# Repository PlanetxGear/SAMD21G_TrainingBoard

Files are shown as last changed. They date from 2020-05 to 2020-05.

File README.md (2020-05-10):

# Microchip SAMD21G Training Board for 「SAMファミリ活用ガイドブック」.
---
## Description
後閑哲也氏の著書[ＳＡＭファミリ活用ガイドブック][1](ISBN 978-4-297-11291-2)に出てくるトレーニングボードをKiCADで書き起こした回路図とガーバーデータです。
これは[KiCAD][2]によって描かれています。　この資料が皆さんの学習の一助となれば幸いです。

## Picture
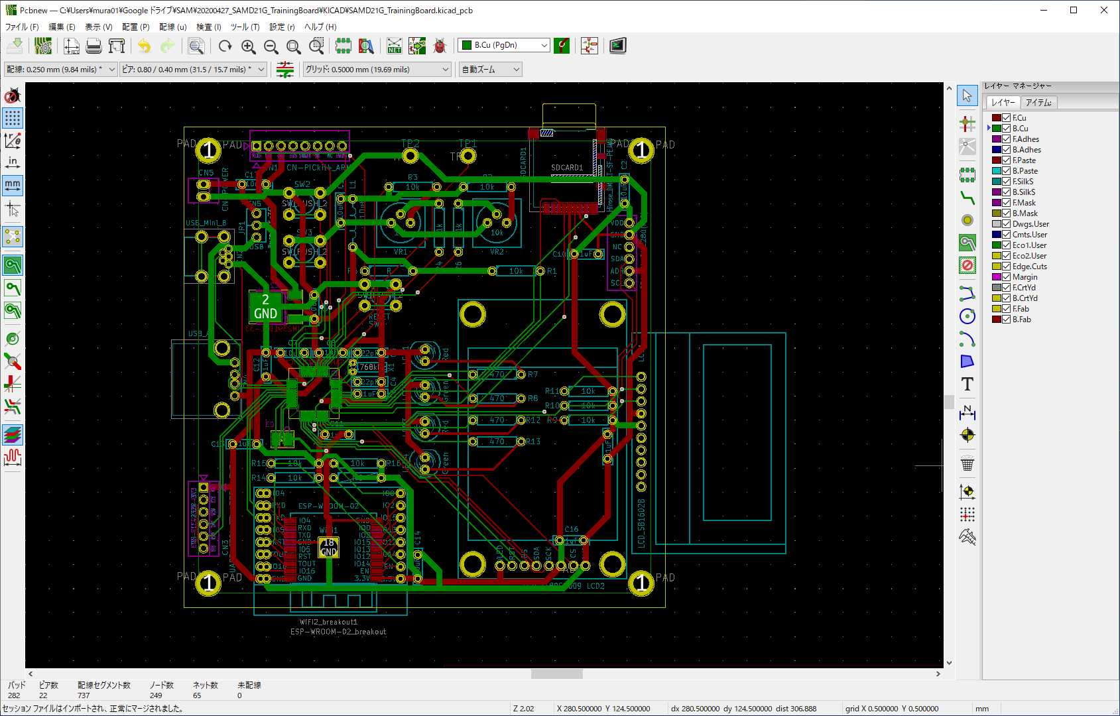
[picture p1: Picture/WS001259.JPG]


## References.
 * <https://www.microchip.com/wwwproducts/en/ATsamd21g18>
 * <http://www.picfun.com/picbookZ3.html>
 * <https://gihyo.jp/book/2020/978-4-297-11291-2>

## Licence
[MIT]<https://en.wikipedia.org/wiki/MIT_License> <https://ja.wikipedia.org/wiki/MIT_License>

## Author
Hiroshi Murakami  
<https://www.planetxgear.com/>  

[1]: https://gihyo.jp/book/2020/978-4-297-11291-2 
[2]: https://kicad-pcb.org/

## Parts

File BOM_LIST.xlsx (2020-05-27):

■SAMファミリ活用ガイドブック、トレーニングボード部品表 2020/05/07
※価格は、2020/05/07時点の調査によるものです。
※プリント基板の導通確認はできていません。
ref | value5 | part | Part Name | 購入先 | 購入先コード | 数量 | 単価 | 金額 | 備考1
IC1 | SAMD21G18A | SAMD21G18A | SAMD21G18A | 秋月電子通商 | I-09837 | 1 | 530 | 530
IC2 | NJM2391DL1-33 | NJM2391DL1-33 | NJM2391DL1-33 | 秋月電子通商 | I-02252 | 1 | 50 | 50 | 4個入り￥200
IC3 | GT20L16J1Y | GT20L16J1Y | GT20L16J1Y | スイッチサイエンス | SSCI-022729 | 1 | 155 | 155 | 2個入り￥310(税抜き)
LCD1 | LCD_SB1602B | LCD_I2C_SB1602B | LCD SB1602B | ストロベリーリナックス | 27001 | 1 | 667 | 667
LCD2 | LCD_Z180SN009 | LCD_Z180SN009 | LCD Z180SN009 | アイテンドー | M-Z18SPI-2PB | 1 | 950 | 950
LED1 | Red | LED | LED 5mm (OSDR5113A) | 秋月電子通商 | I-11655 | 1 | 20 | 20
LED2 | Green | LED | LED 5mm (OSNG5113A) | 秋月電子通商 | I-11656 | 1 | 20 | 20
LED3 | Red | LED | LED 5mm (OSDR5113A) | 秋月電子通商 | I-11655 | 1 | 20 | 20
LED4 | Green | LED | LED 5mm (OSNG5113A) | 秋月電子通商 | I-11656 | 1 | 20 | 20
SDCARD1 | Hirose_DM3AT-SF-PEJM5 | SD_CARD_microsdSD_HC_Hirose_DM3AT-SF-PEJM5 | microsdSD_HC_Hirose_DM3AT-SF-PEJM5 | 秋月電子通商 | C-02395 | 1 | 140 | 140
SE1 | CN-BME280(I2C) | CN-BME280(I2C) | BME280 | 秋月電子通商 | K-09421 | 1 | 1080 | 1080
SW1 | SW_PUSH_2 | SW_PUSH | 基板タクトスイッチ(赤) | 秋月電子通商 | P-03646 | 1 | 10 | 10
SW2 | SW_PUSH_2 | SW_PUSH | 基板タクトスイッチ(黒) | 秋月電子通商 | P-03647 | 1 | 10 | 10
SW3 | SW_PUSH_2 | SW_PUSH | 基板タクトスイッチ(黒) | 〃 | 〃 | 1 | 10 | 10
TP1 | TP1 | CN-1 | チェック端子(赤) | 秋月電子通商 | P-07588 | 1 | 20 | 20 | 10個入り￥200
TP2 | TP2 | CN-1 | チェック端子(黒) | 秋月電子通商 | P-07591 | 1 | 20 | 20 | 10個入り￥200
VR1 | 10k | RVR | TSR3386K-EY5-103TR | 秋月電子通商 | P-06110 | 1 | 50 | 50
VR2 | 10k | RVR | 〃 | 〃 | 〃 | 1 | 50 | 50
WiFi1 | ESP-WROOM-02 | ESP-WROOM-02 | ESP-WROOM-02 | 秋月電子通商 | M-09607 | 1 | 250 | 250
(WiFi2_breakout1) | ESP-WROOM-02_breakout | (ESP-WROOM-02) | (ESP-WROOM-02ピッチ変換キット) | (秋月電子通商/スイッチサイエンス) | (K-13646/SSCI-023474) | (1) | (580/842) |  | ※不要
X1 | 32.768kHz | Crystal | VT200,32.768kHz | 秋月電子通商 | P-04005 | 1 | 30 | 30
L1 | 10uH | L | マイクロインダクター 10uF | 秋月電子通商 | P-04932 | 1 | 10 | 10 | 10個入り￥100
C1 | 10uF | C | 積層セラミックコンデンサ5mmピッチ 10uF | 秋月電子通商 | P-03095 | 1 | 20 | 20 | 10個入り￥200
C2 | 10uF | C | 〃 | 〃 | 〃 | 1 | 20 | 20
C5 | 10uF | C | 〃 | 〃 | 〃 | 1 | 20 | 20
C7 | 10uF | C | 〃 | 〃 | 〃 | 1 | 20 | 20
C14 | 10uF | C | 〃 | 〃 | 〃 | 1 | 20 | 20
C17 | 10uF | C | 〃 | 〃 | 〃 | 1 | 20 | 20
C6 | 1uF | C | 積層セラミックコンデンサ5mmピッチ 1uF | 秋月電子通商 | P-03093 | 1 | 10 | 10 | 10個入り￥100
C8 | 1uF | C | 〃 | 〃 | 〃 | 1 | 10 | 10
C10 | 1uF | C | 〃 | 〃 | 〃 | 1 | 10 | 10
C11 | 1uF | C | 〃 | 〃 | 〃 | 1 | 10 | 10
C12 | 1uF | C | 〃 | 〃 | 〃 | 1 | 10 | 10
C13 | 1uF | C | 〃 | 〃 | 〃 | 1 | 10 | 10
C15 | 1uF | C | 〃 | 〃 | 〃 | 1 | 10 | 10
C16 | 1uF | C | 〃 | 〃 | 〃 | 1 | 10 | 10
C3 | 22pF | C | 積層セラミックコンデンサ5mmピッチ 22pF | 秋月電子通商 | P-08094 | 1 | 10 | 10 | 10個入り￥100
C4 | 22pF | C | 〃 | 〃 | 〃 | 1 | 10 | 10
CN2 | USB_Mini_B | CN_USB_Mini_B | USB type B Mini connector | 秋月電子通商 | C-02235 | 1 | 50 | 50 | 4個入り￥200
CN4 | USB_A | CN_USB_A | USB type A connector | 秋月電子通商 | C-11551 | 1 | 50 | 50
CN1 | CN-PICkit4_ARM | CN-PICkit4_ARM | ピンヘッダ | - | - |  |  | 0 | ※下記ピンヘッダ切断
CN3 | UART-FTDI-TTL-232R-3V3 | CN-UART-FTDI-TTL-232R-3V3 | ピンヘッダ | - | - |  |  | 0 | 〃
CN5 | CN-POWER | CN-POWER | ピンヘッダ | - | - |  |  | 0 | 〃
JP1 | Jumper_3P | Jumper_NO_Small_3P | ピンヘッダ | - | - |  |  | 0 | 〃
 |  |  | ピンヘッダ L型 1 x 40 |  | C-01627 | 1 | 50 | 50
 |  |  | 丸ピンＩＣ用連結ソケット |  | P-01382 | 1 | 230 | 230
 |  |  | 丸ピンＩＣ用ソケット |  | P-01591 | 1 | 150 | 150
－ | － | － | ジャンパーピン赤 | 秋月電子通商 | P-03688 | 1 | 4 | 4 | 25個入り￥100
R1 | 10k | R | カーボン抵抗 1/6W 10kΩ | 秋月電子通商 | R-16103 | 1 | 1 | 1 | 100個入り￥100
R2 | 10k | R | 〃 | 〃 | 〃 | 1 | 1 | 1
R3 | 10k | R | 〃 | 〃 | 〃 | 1 | 1 | 1
R5 | 10k | R | 〃 | 〃 | 〃 | 1 | 1 | 1
R9 | 10k | R | 〃 | 〃 | 〃 | 1 | 1 | 1
R10 | 10k | R | 〃 | 〃 | 〃 | 1 | 1 | 1
R11 | 10k | R | 〃 | 〃 | 〃 | 1 | 1 | 1
R14 | 10k | R | 〃 | 〃 | 〃 | 1 | 1 | 1
R15 | 10k | R | 〃 | 〃 | 〃 | 1 | 1 | 1
R16 | 10k | R | 〃 | 〃 | 〃 | 1 | 1 | 1
R4 | 1k | R | カーボン抵抗 1/6W 1kΩ | 秋月電子通商 | R-16102 | 1 | 1 | 1 | 100個入り￥100
R6 | 1k | R | 〃 | 〃 | 〃 | 1 | 1 | 1
R7 | 470 | R | カーボン抵抗 1/6W 470Ω | 秋月電子通商 | R-16471 | 1 | 1 | 1 | 100個入り￥100
R8 | 470 | R | 〃 | 〃 | 〃 | 1 | 1 | 1
R12 | 470 | R | 〃 | 〃 | 〃 | 1 | 1 | 1
R13 | 470 | R | 〃 | 〃 | 〃 | 1 | 1 | 1
R99 | NC | R | － | － | － |  |  | 0 | ※不要
 |  |  |  |  |  | 部品金額合計 |  | 4882 | 円
 |  |  |  |  |  | 消費税 |  | 488.2 | 円
 |  |  |  |  |  | 小計 |  | 5370.2 | 円
 |  |  | プリント基板(10枚,送料込み)=$29.9+$17.45=$47.35 |  |  | 1 | 527 | 527 | (￥5269/10枚=￥527)
 |  |  |  |  |  | 送料・梱包代（レターパックライト） |  | 370 | 円
 |  |  |  |  |  | 合計 |  | 6267.2 | 円

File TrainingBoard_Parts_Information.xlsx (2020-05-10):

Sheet: SAMD21G18A
1 | PA00/XIN32
2 | PA01/XOUT32
3 | PA02/AN0/VO
4 | PA03/AN1
5 | GNDA
6 | VDDA
7 | PB08/AN2
8 | PB09/AN3
9 | PA04/AN4
10 | PA05/AN5
11 | PA06/AN6
12 | PA07/AN7
13 | PA08/I2C
14 | PA09/I2C
15 | PA10
16 | PA11
17 | VDDIO
18 | GND
19 | PB10
20 | PB11
21 | PA12/I2C
22 | PA13/I2C
23 | PA14/XIN
24 | PA15/XOUT
25 | PA16/I2C
26 | PA17/I2C
27 | PA18/AC
28 | PA19/AC
29 | PA20
30 | PA21
31 | PA22/I2C
32 | PA23/I2C
33 | PA24/D-
34 | PA25/D+
35 | GND1
36 | VDDIO1
37 | PB22
38 | PB23
39 | PA27
40 | RSTEN
41 | PA28
42 | GND2
43 | VDDCORE
44 | VDDIN
45 | PA30/SWCLK
46 | PA31/SWDIO
47 | PB02/AN10
48 | PB03/AN11
PICkit4とSAMの接続
PICkit4ユーザガイドAppendix

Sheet: GT20L16J1Y
日本語フォントROM GT20L16J1Y チップ 2個入り
 | https://www.switch-science.com/catalog/2272/
 | http://www.genitop.com/admin/upload/20150511144125736.pdf
 | コード番号 | SSCI-022729

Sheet: Sheet1
★1.8インチ★TFT液晶with基板★SPI★ [M-Z18SPI-2PB]
 | Z180SN009
 | https://www.aitendo.com/product/15420
 | 基板寸法：58x35x1.2mm

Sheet: ESP-WROOM-02
ESP-WROOM-02ピッチ変換済みモジュール《シンプル版》
 | https://www.switch-science.com/catalog/2341/
 | http://doc.switch-science.com/schematic/ESP-WROOM-02/ESP-WROOM-02_breakout_simple.pdf
 | ESP-WROOM-02モジュールと各端子の接続
 | ESP-WROOM-02 | 当モジュール
 | 3V3 | 3V3
 | EN | EN
 | IO14 | 未接続
 | IO12 | 未接続
 | IO13 | 未接続
 | IO15 | SJ1経由でGNDに接続（裏面）
 | IO2 | SJ2（裏面）、IO2
 | IO0 | SJ3（裏面）、IO0
 | GND | GND
 | IO4 | 未接続
 | RXD | RXD
 | TXD | TXD
 | GND | GND
 | IO5 | 未接続
 | RST | RST
 | TOUT | 未接続
 | IO16 | 未接続
 | GND | GND
Ｗｉ－Ｆｉモジュール ＥＳＰ－ＷＲＯＯＭ－０２
 | http://akizukidenshi.com/catalog/g/gM-09607/
 | ESP-WROOM-02(4MB)]
 | 通販コード | M-09607
ＥＳＰ－ＷＲＯＯＭ－０２ピッチ変換キット
 | AE-ESP-WROOM-02-1100MIL
 | 通販コード | K-13646
ESP-WROOM-02ピッチ変換済みモジュール《フル版》
 | https://www.switch-science.com/catalog/2347/

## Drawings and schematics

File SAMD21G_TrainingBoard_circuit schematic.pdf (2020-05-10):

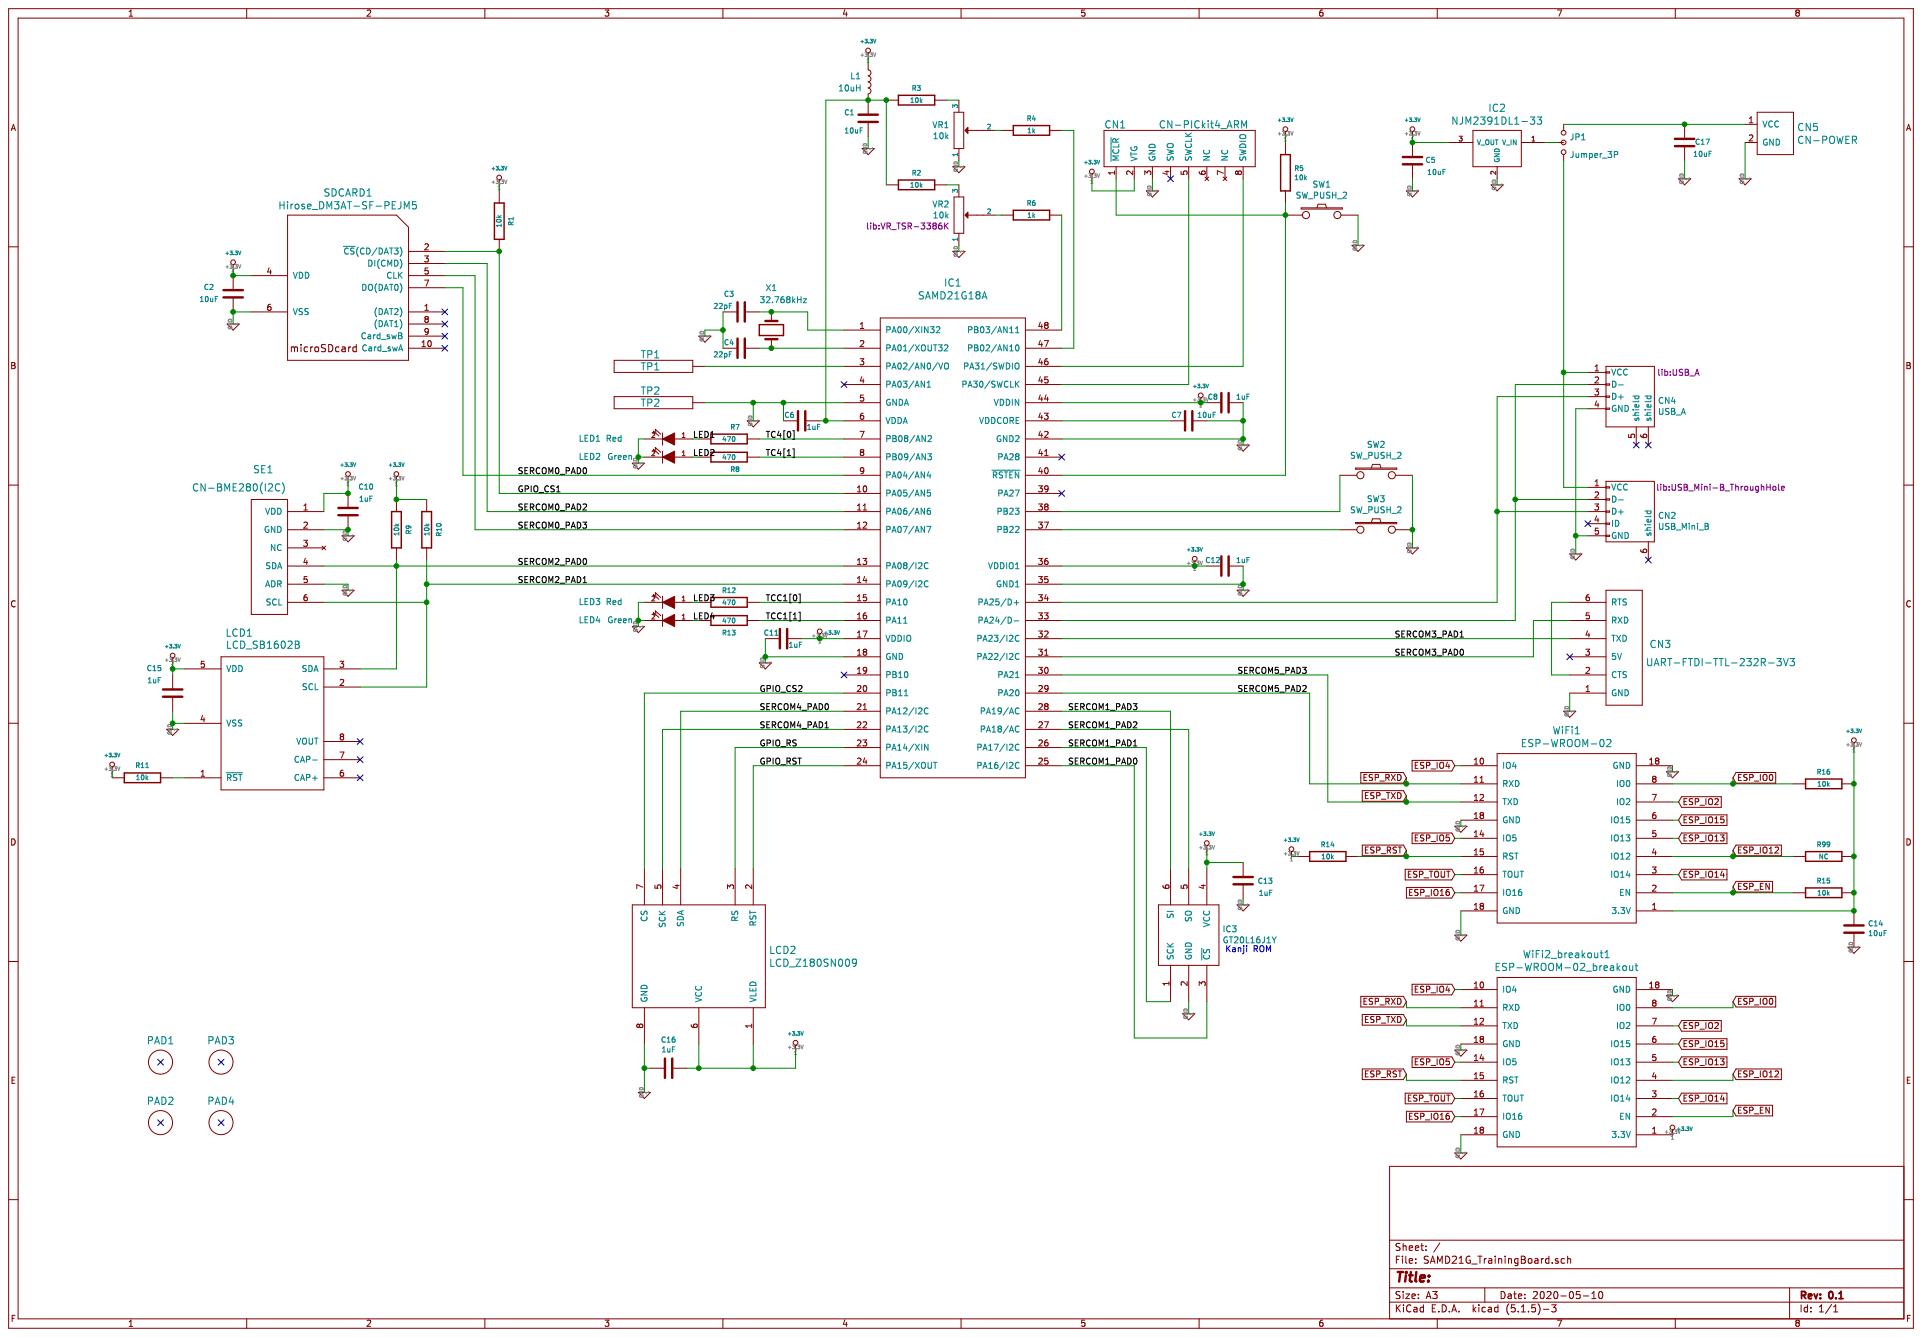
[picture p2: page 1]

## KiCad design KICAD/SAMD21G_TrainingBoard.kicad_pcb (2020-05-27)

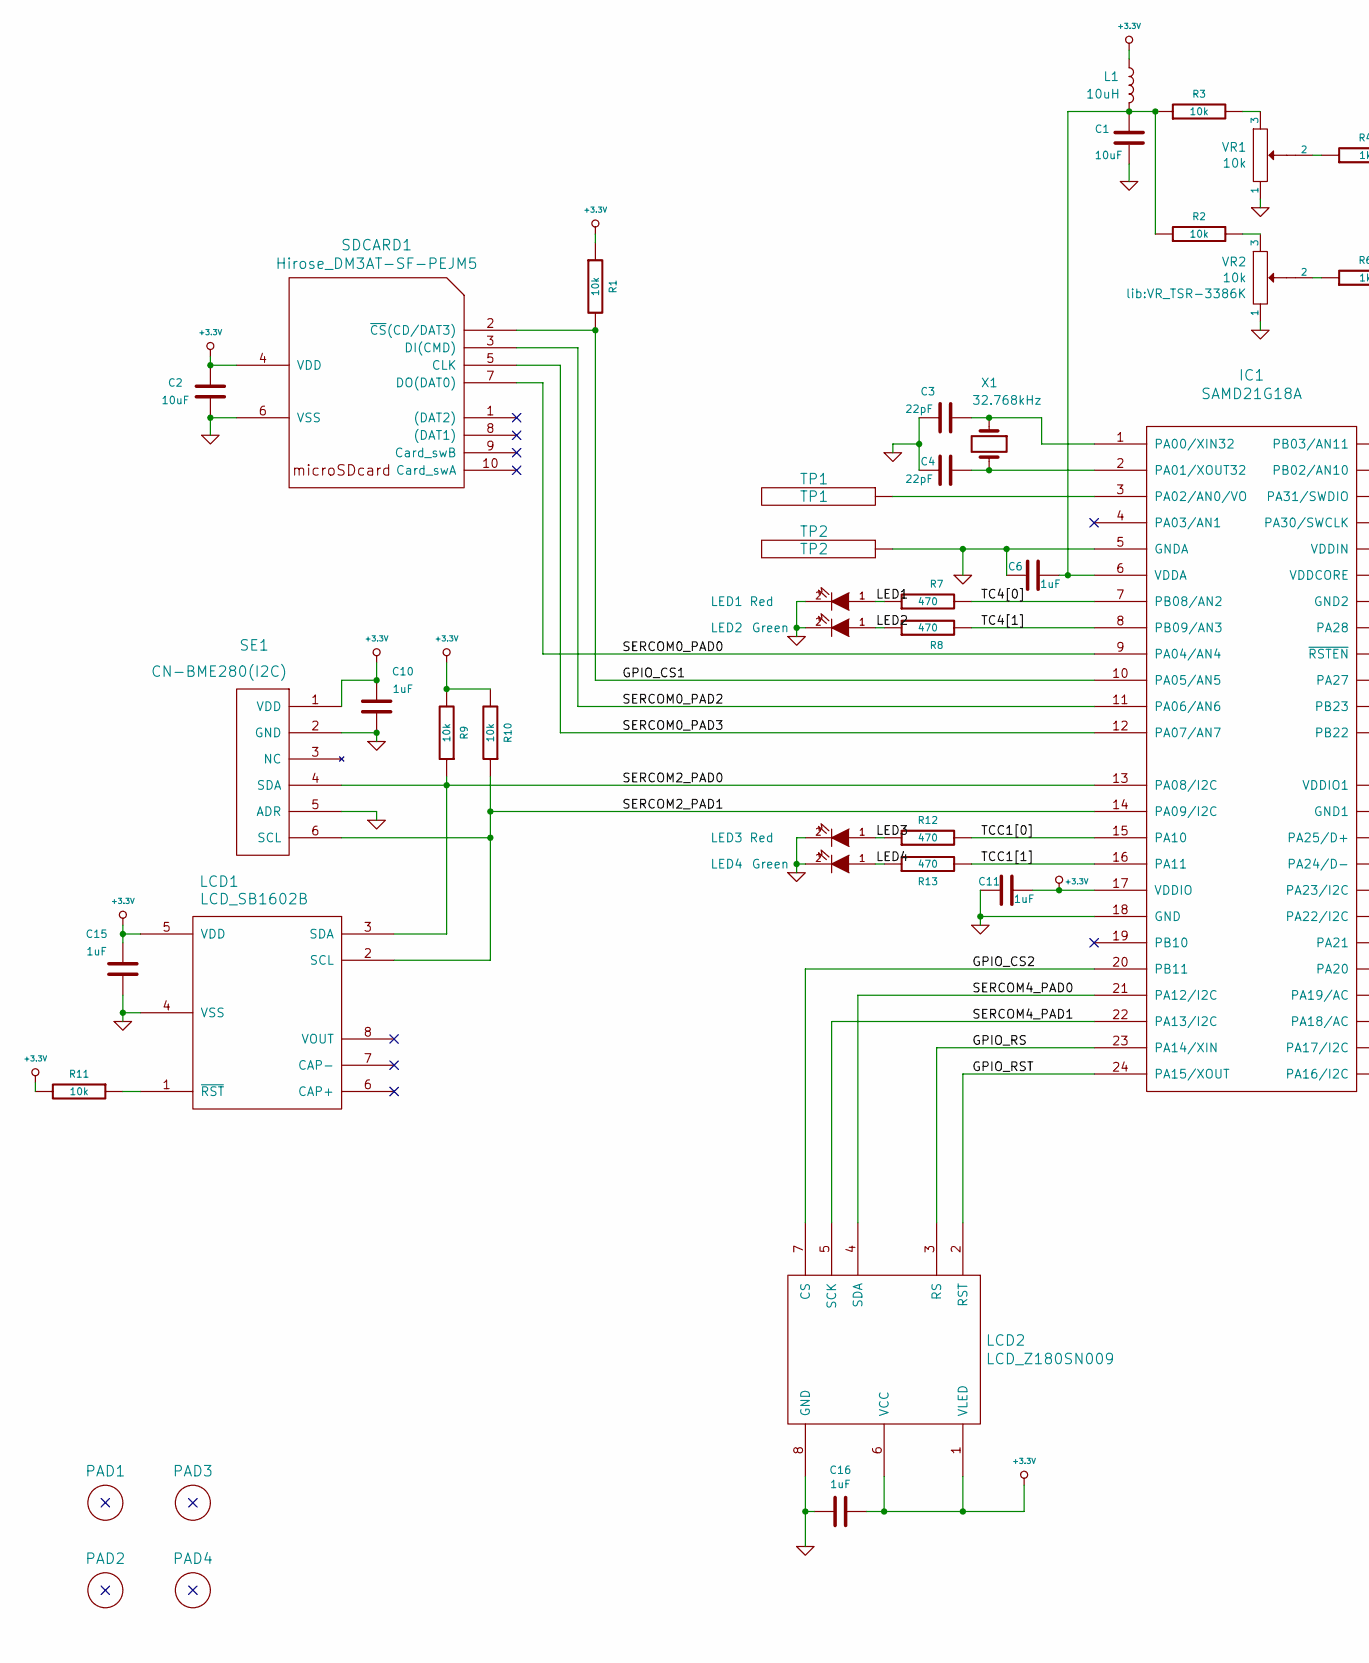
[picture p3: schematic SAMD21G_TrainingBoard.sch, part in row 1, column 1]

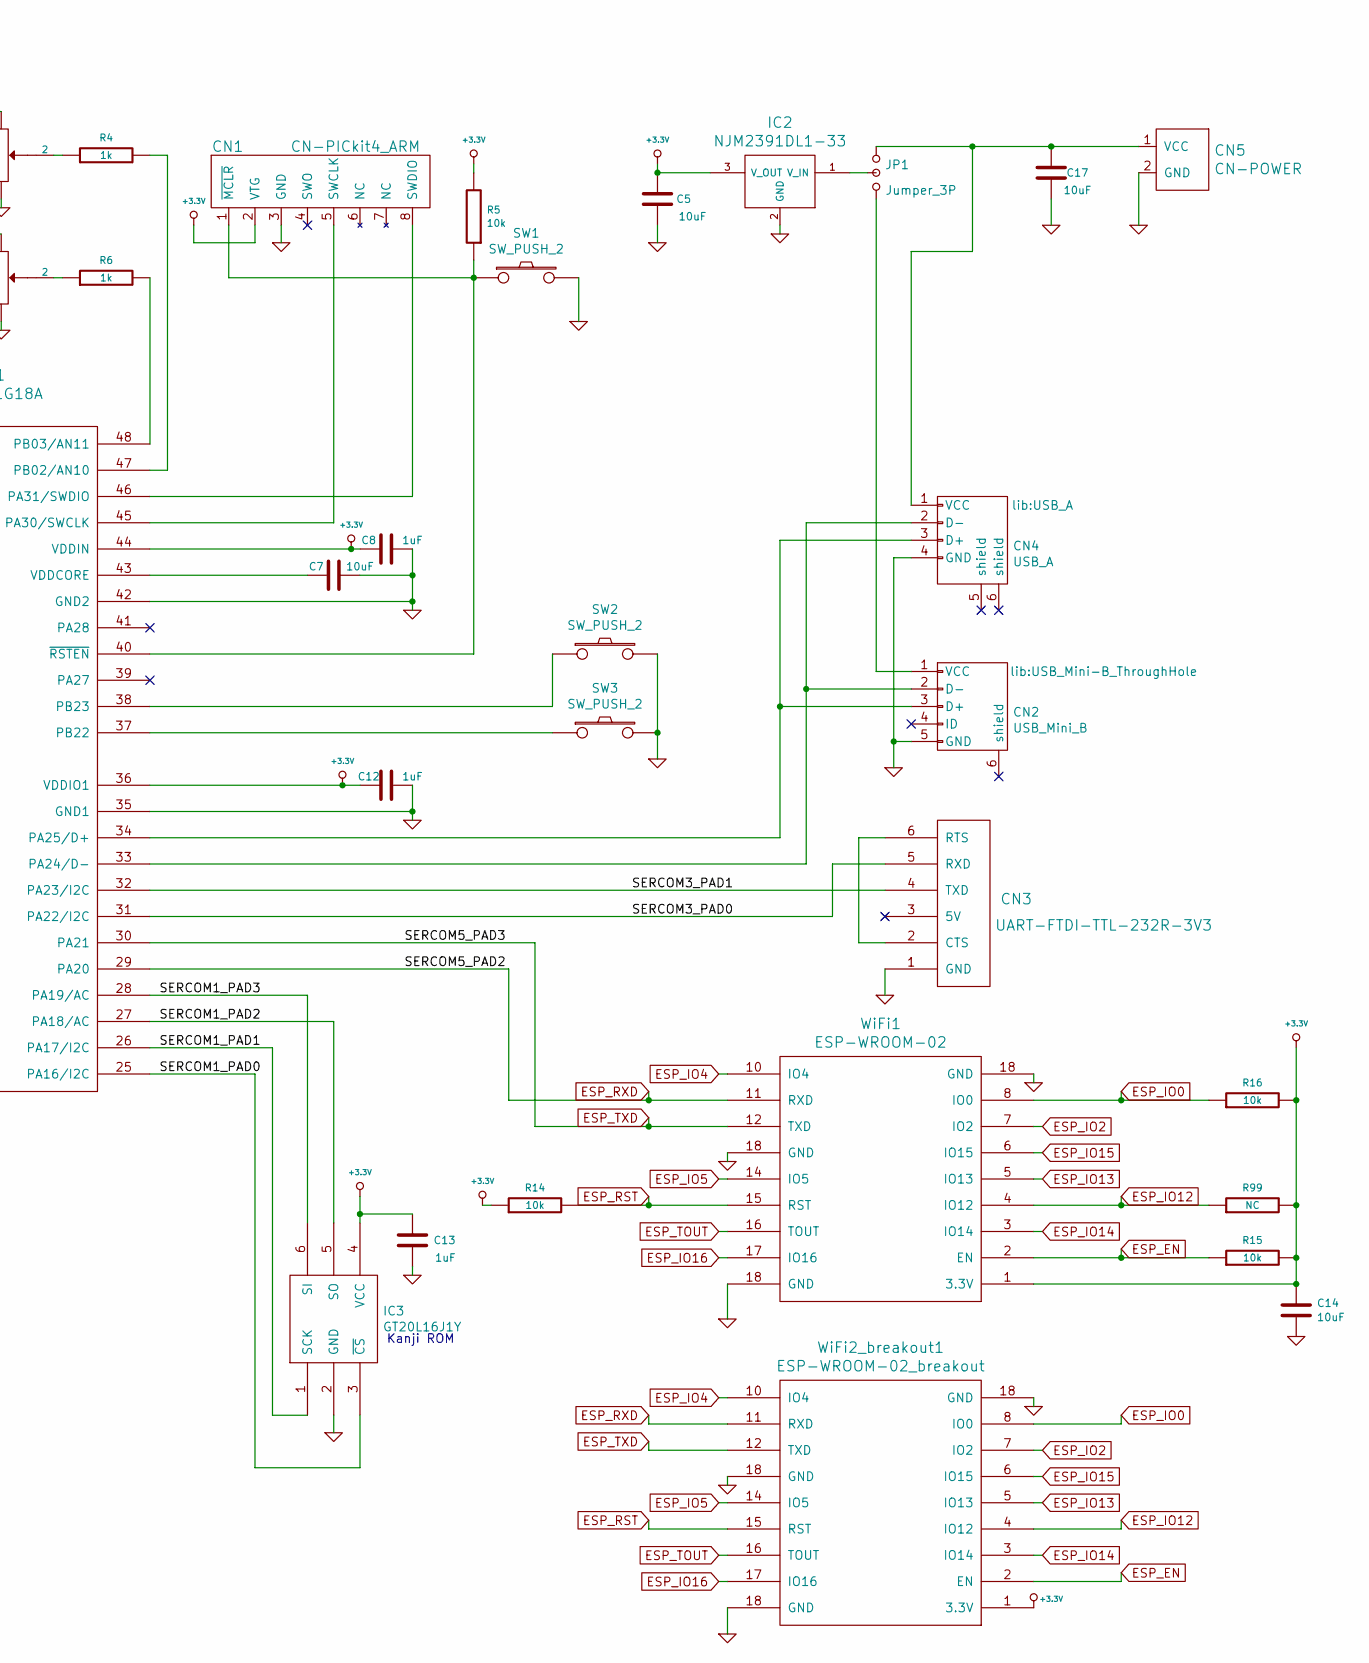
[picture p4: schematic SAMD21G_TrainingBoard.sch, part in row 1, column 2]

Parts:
C1, C2, C5, C7, C14, C17: 10uF; C2_MU
C3, C4: 22pF; C2_MU
C6, C8, C10, C11, C12, C13, C15, C16: 1uF; C2_MU
CN1: CN-PICkit4_ARM; PINHEAD1-PICkit4_ARM
CN2: USB_Mini_B; USB_Mini-B_ThroughHole
CN3: UART-FTDI-TTL-232R-3V3; PINHEAD1-FTDI-TTL-232R-3V3
CN4: USB_A
CN5: CN-POWER; PINHEAD1-2_MU2
IC1: SAMD21G18A; TQFP-48_7x7mm_Pitch0.5mm
IC2: NJM2391DL1-33; TO-252-2
IC3: GT20L16J1Y; SOT-23-6_Handsoldering
JP1: Jumper_3P; JUMPER1-3
L1: 10uH; L4_MU
LCD1: LCD_SB1602B
LCD2: LCD_Z180SN009
LED1, LED3: Red; LED-5MM_AK
LED2, LED4: Green; LED-5MM_AK
PAD1, PAD2, PAD3, PAD4: PAD; PAD3mmX5mm
R1, R2, R3, R5, R9, R10, R11, R14, R15, R16: 10k; R4_MU
R4, R6: 1k; R4_MU
R7, R8, R12, R13: 470; R4_MU
R99: NC; R4_MU
SDCARD1: Hirose_DM3AT-SF-PEJM5; SD_CARD_microsdSD_HC_Hirose_DM3AT-SF-PEJM5
SE1: CN-BME280(I2C); CN_BME280(I2C)
SW1, SW2, SW3: SW_PUSH_2; SW_PUSH-6mm_AK
TP1: TP1; PAD1.6mmX3m
TP2: TP2; PAD1.6mmX3m
VR1, VR2: 10k; VR_TSR-3386K
WiFi1: ESP-WROOM-02
WiFi2_breakout1: ESP-WROOM-02_breakout
X1: 32.768kHz; X_TAL_VT200

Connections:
+3.3V: C2.2, C5.2, C8.2, C10.2, C11.1, C12.2, C13.1, C14.2, C15.2, C16.1, CN1.2 (VTG), IC1.17 (VDDIO), IC1.36 (VDDIO1), IC1.44 (VDDIN), IC2.3 (V_OUT), IC3.4 (VCC), L1.1, LCD1.5 (VDD), LCD2.1 (VLED), LCD2.6 (VCC), R1.1, R5.2, R9.2, R10.2, R11.2, R14.1, R15.2, R16.2, R99.2, SDCARD1.4 (VDD), SE1.1 (VDD), WiFi1.1 (3.3V), WiFi2_breakout1.1 (3.3V)
/GPIO_CS1: IC1.10 (PA05/AN5), R1.2, SDCARD1.2 (~CS~(CD/DAT3))
/GPIO_CS2: IC1.20 (PB11), LCD2.7 (CS)
/GPIO_RS: IC1.23 (PA14/XIN), LCD2.3 (RS)
/GPIO_RST: IC1.24 (PA15/XOUT), LCD2.2 (RST)
/LED1: LED1.1 (A), R7.1
/LED2: LED2.1 (A), R8.1
/LED3: LED3.1 (A), R12.1
/LED4: LED4.1 (A), R13.1
/SERCOM0_PAD0: IC1.9 (PA04/AN4), SDCARD1.7 (DO(DAT0))
/SERCOM0_PAD2: IC1.11 (PA06/AN6), SDCARD1.3 (DI(CMD))
/SERCOM0_PAD3: IC1.12 (PA07/AN7), SDCARD1.5 (CLK)
/SERCOM1_PAD0: IC1.25 (PA16/I2C), IC3.3 (~CS)
/SERCOM1_PAD1: IC1.26 (PA17/I2C), IC3.1 (SCK)
/SERCOM1_PAD2: IC1.27 (PA18/AC), IC3.5 (SO)
/SERCOM1_PAD3: IC1.28 (PA19/AC), IC3.6 (SI)
/SERCOM2_PAD0: IC1.13 (PA08/I2C), LCD1.3 (SDA), R9.1, SE1.4 (SDA)
/SERCOM2_PAD1: IC1.14 (PA09/I2C), LCD1.2 (SCL), R10.1, SE1.6 (SCL)
/SERCOM3_PAD0: CN3.5 (RXD), IC1.31 (PA22/I2C)
/SERCOM3_PAD1: CN3.4 (TXD), IC1.32 (PA23/I2C)
/SERCOM4_PAD0: IC1.21 (PA12/I2C), LCD2.4 (SDA)
/SERCOM4_PAD1: IC1.22 (PA13/I2C), LCD2.5 (SCK)
/TC4[0]: IC1.7 (PB08/AN2), R7.2
/TC4[1]: IC1.8 (PB09/AN3), R8.2
/TCC1[0]: IC1.15 (PA10), R12.2
/TCC1[1]: IC1.16 (PA11), R13.2
ESP_EN: R15.1, WiFi1.2 (EN), WiFi2_breakout1.2 (EN)
ESP_IO0: R16.1, WiFi1.8 (IO0), WiFi2_breakout1.8 (IO0)
ESP_IO2: WiFi1.7 (IO2), WiFi2_breakout1.7 (IO2)
ESP_IO4: WiFi1.10 (IO4), WiFi2_breakout1.10 (IO4)
ESP_IO5: WiFi1.14 (IO5), WiFi2_breakout1.14 (IO5)
ESP_IO12: R99.1, WiFi1.4 (IO12), WiFi2_breakout1.4 (IO12)
ESP_IO13: WiFi1.5 (IO13), WiFi2_breakout1.5 (IO13)
ESP_IO14: WiFi1.3 (IO14), WiFi2_breakout1.3 (IO14)
ESP_IO15: WiFi1.6 (IO15), WiFi2_breakout1.6 (IO15)
ESP_IO16: WiFi1.17 (IO16), WiFi2_breakout1.17 (IO16)
ESP_RST: R14.2, WiFi1.15 (RST), WiFi2_breakout1.15 (RST)
ESP_RXD: IC1.29 (PA20), WiFi1.11 (RXD), WiFi2_breakout1.11 (RXD)
ESP_TOUT: WiFi1.16 (TOUT), WiFi2_breakout1.16 (TOUT)
ESP_TXD: IC1.30 (PA21), WiFi1.12 (TXD), WiFi2_breakout1.12 (TXD)
GND: C1.2, C2.1, C3.2, C4.2, C5.1, C6.2, C7.1, C8.1, C10.1, C11.2, C12.1, C13.2, C14.1, C15.1, C16.2, C17.1, CN1.3 (GND), CN2.5 (GND), CN3.1 (GND), CN4.4 (GND), CN5.2 (GND), IC1.5 (GNDA), IC1.18 (GND), IC1.35 (GND1), IC1.42 (GND2), IC2.2 (GND), IC3.2 (GND), LCD1.4 (VSS), LCD2.8 (GND), LED1.2 (K), LED2.2 (K), LED3.2 (K), LED4.2 (K), SDCARD1.6 (VSS), SE1.2 (GND), SE1.5 (ADR), SW1.2, SW2.2, SW3.2, TP2.1, VR1.1, VR2.1, WiFi1.18 (GND), WiFi2_breakout1.18 (GND)
unnamed: C1.1, C6.1, IC1.6 (VDDA), L1.2, R2.1, R3.1
unnamed: C3.1, IC1.1 (PA00/XIN32), X1.1
unnamed: C4.1, IC1.2 (PA01/XOUT32), X1.2
unnamed: C7.2, IC1.43 (VDDCORE)
unnamed: C17.2, CN4.1 (VCC), CN5.1 (VCC), JP1.1
unnamed: CN1.1 (~MCLR), IC1.40 (~RSTEN), R5.1, SW1.1
unnamed: CN1.5 (SWCLK), IC1.45 (PA30/SWCLK)
unnamed: CN1.8 (SWDIO), IC1.46 (PA31/SWDIO)
unnamed: CN2.1 (VCC), JP1.3
unnamed: CN2.2 (D-), CN4.2 (D-), IC1.33 (PA24/D-)
unnamed: CN2.3 (D+), CN4.3 (D+), IC1.34 (PA25/D+)
unnamed: CN3.2 (CTS), CN3.6 (RTS)
unnamed: IC1.3 (PA02/AN0/VO), TP1.1
unnamed: IC1.37 (PB22), SW3.1
unnamed: IC1.38 (PB23), SW2.1
unnamed: IC1.47 (PB02/AN10), R4.2
unnamed: IC1.48 (PB03/AN11), R6.2
unnamed: IC2.1 (V_IN), JP1.2
unnamed: LCD1.1 (~RST), R11.1
unnamed: R2.2, VR2.3
unnamed: R3.2, VR1.3
unnamed: R4.1, VR1.2
unnamed: R6.1, VR2.2

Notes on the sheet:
Kanji ROM

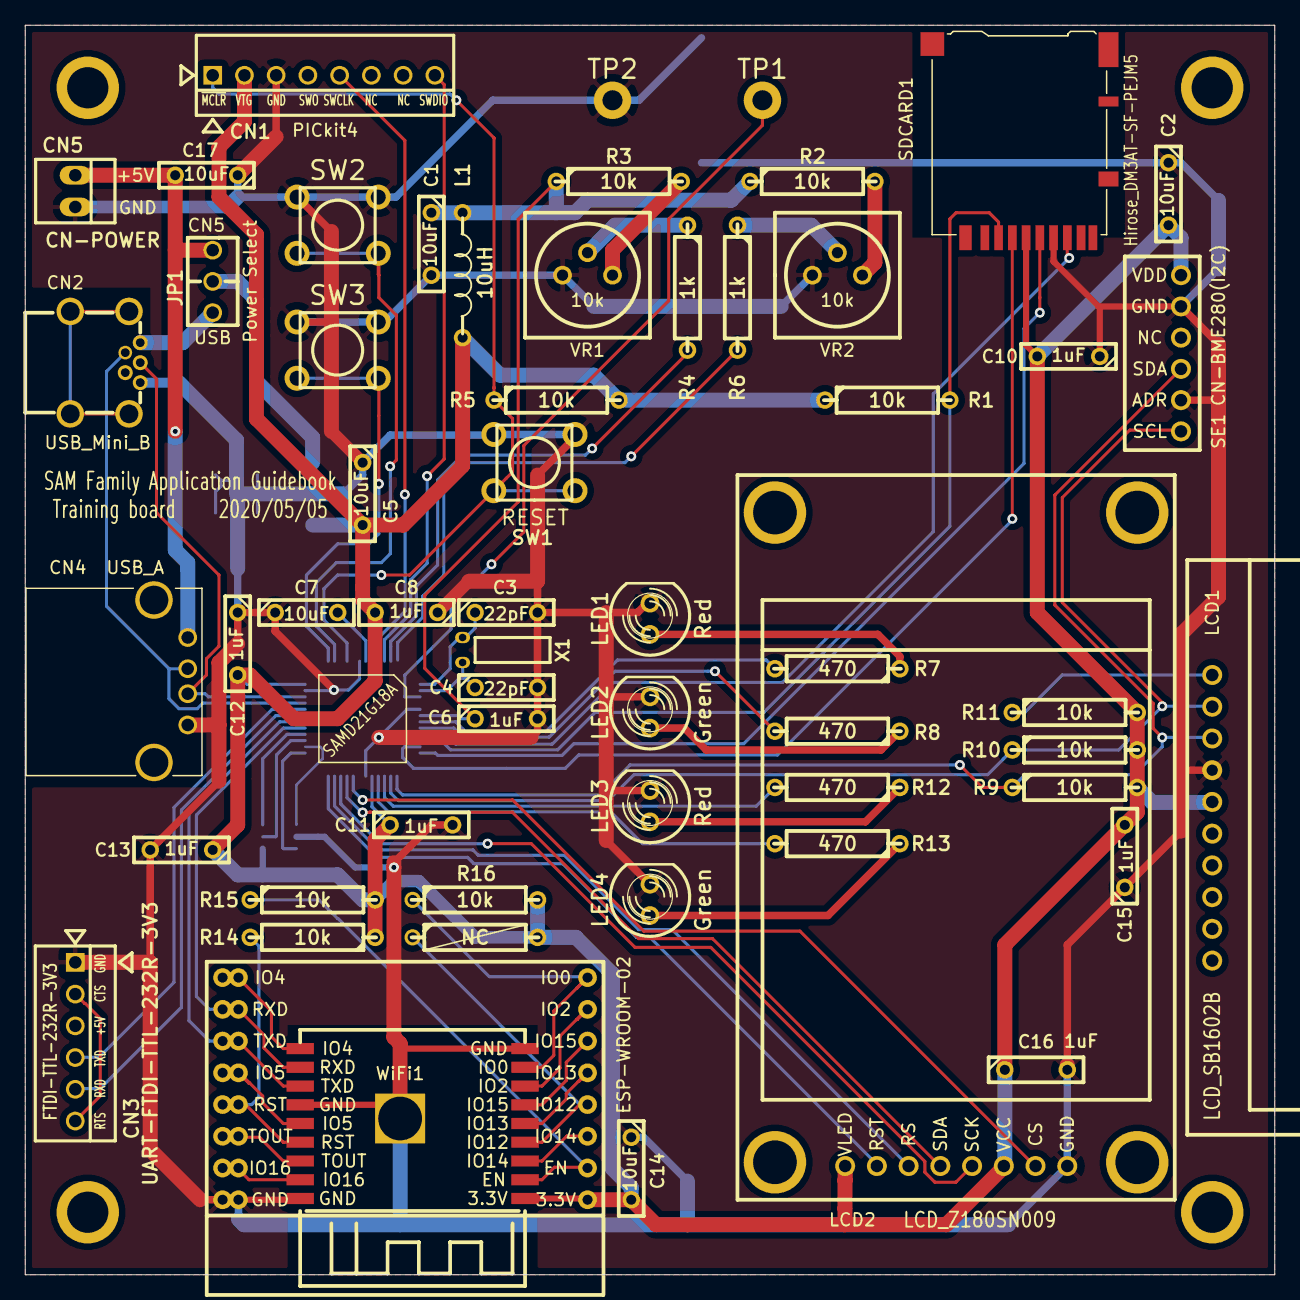
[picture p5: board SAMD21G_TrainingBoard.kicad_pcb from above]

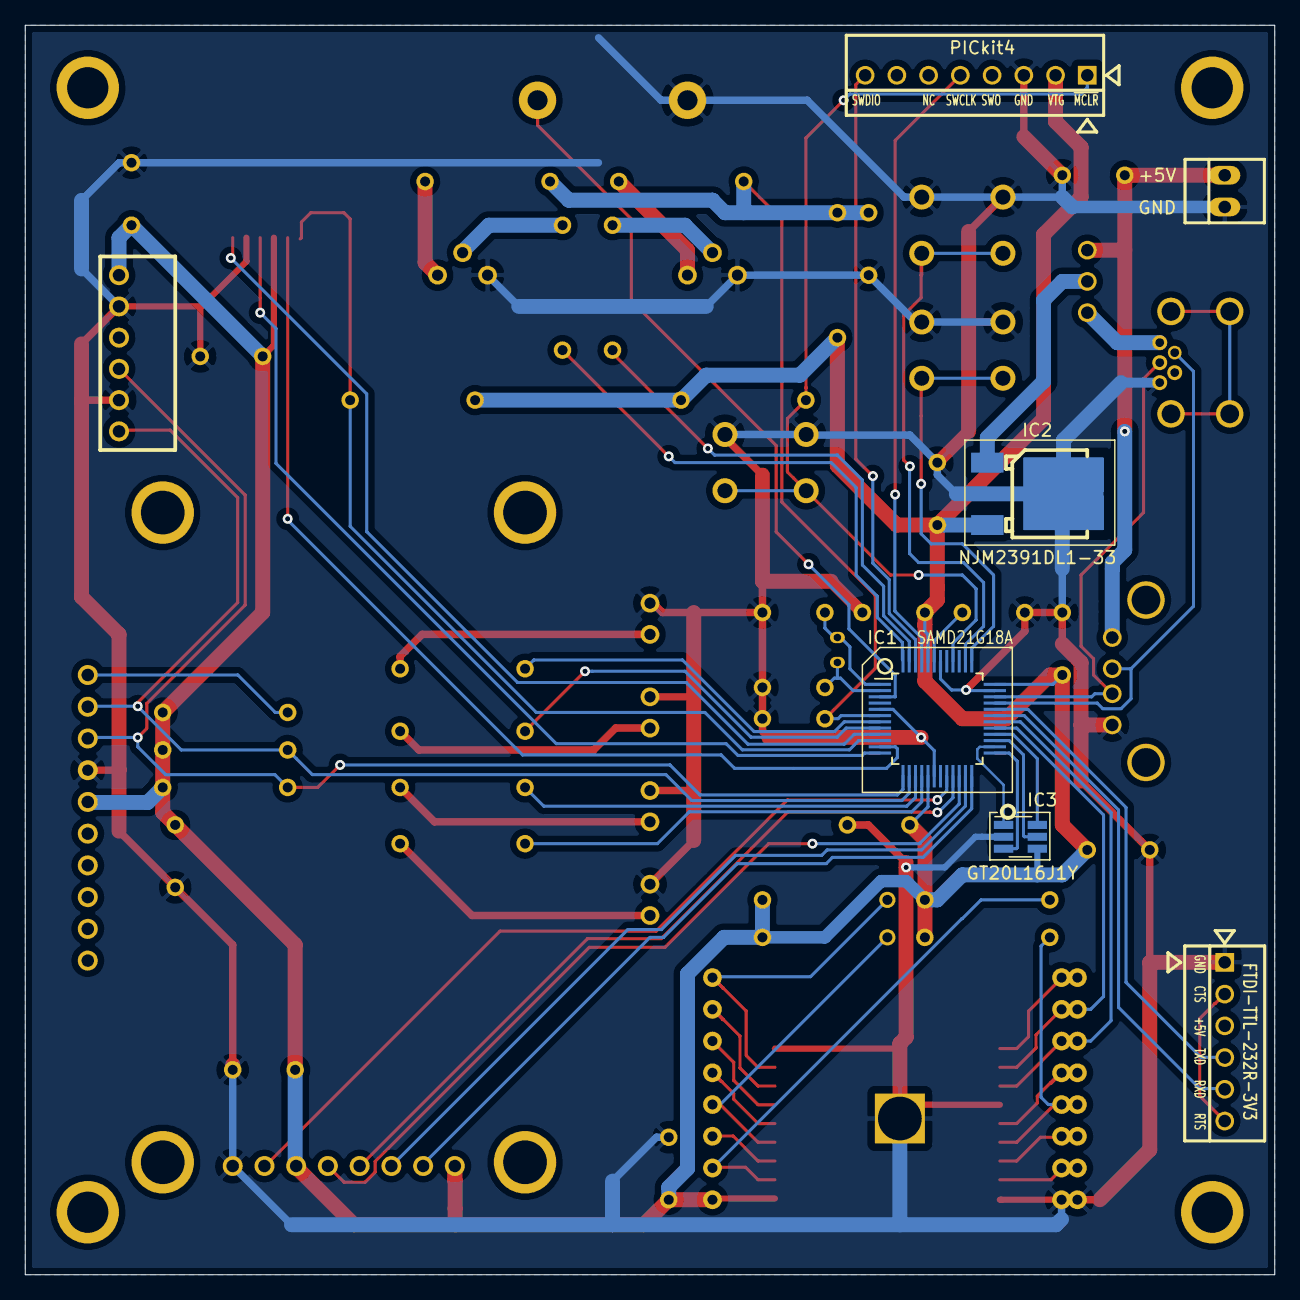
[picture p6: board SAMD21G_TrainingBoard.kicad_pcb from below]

Board: 2 copper layers, 100.0 x 100.0 mm, 65 parts (5 on the bottom side), 64 nets.
